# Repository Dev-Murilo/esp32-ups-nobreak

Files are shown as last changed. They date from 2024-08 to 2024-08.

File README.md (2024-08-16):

# esp32-ups-nobreak

## FIRST VIEW
Click here to go to the first view of main features, pins of 
[esp32-ups-nobreak](https://github.com/Dev-Murilo/esp32-ups-nobreak/tree/main/Doc)

##

O **esp32-ups-nobreak** é um projeto de nobreak (UPS - Uninterruptible Power Supply) que oferece suporte a diferentes aplicações devido à possibilidade de customização tanto por software quanto por hardware.

## Tabela de Conteúdo

- [Histórico do Projeto](#histórico-do-projeto)
  - [Primeira Versão](#primeira-versão)
  - [Segunda Versão](#segunda-versão)
  - [Terceira Versão (Atual)](#terceira-versão-atual)
- [Funcionalidades](#funcionalidades)
- [Configuração do Software Atual](#configuração-do-software-atual)
  - [Telemetria](#telemetria)
  - [Exemplo de Telemetria](#exemplo-de-telemetria)
- [Considerações sobre as Fontes de Alimentação](#considerações-sobre-as-fontes-de-alimentação)
- [Licença](#licença)

## Histórico do Projeto

### Primeira Versão
- Desenvolvido usando o uChip do Arduino Uno.
- Objetivo: Utilização com impressoras 3D.
- Status: Não entrou em produção.
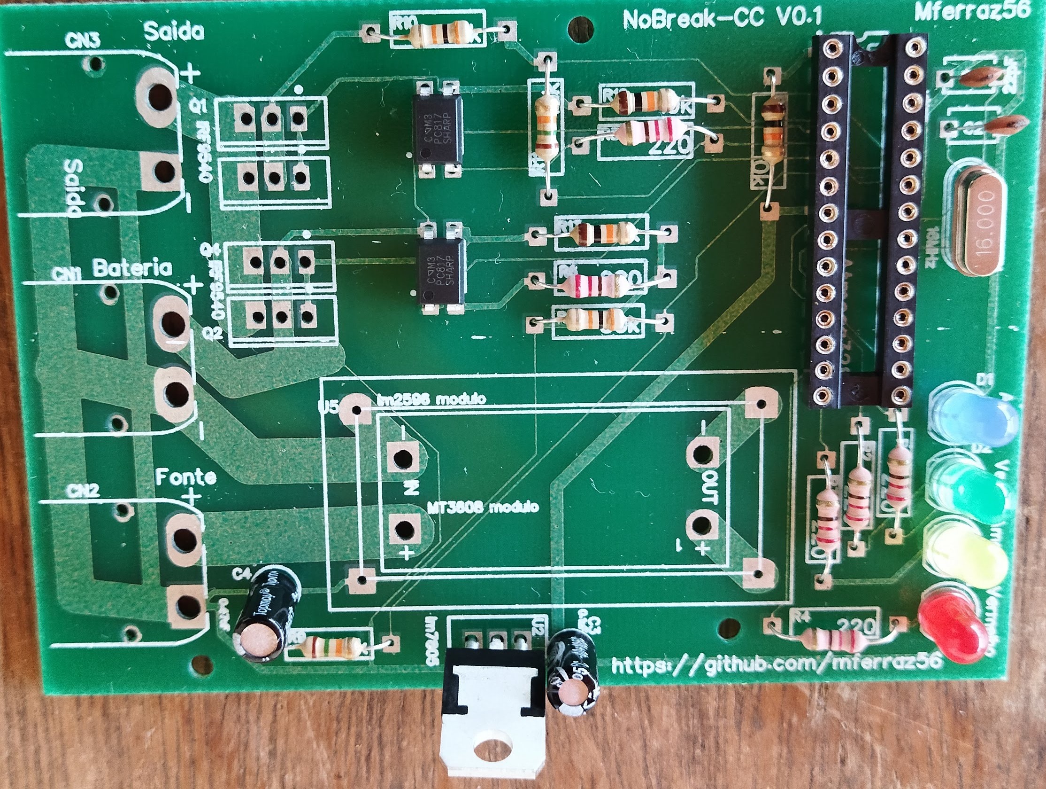
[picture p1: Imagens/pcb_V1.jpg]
pcb_V1


### Segunda Versão
- Critérios:
  - Utilização da menor área possível.
  - Teste e validação em tempo recorde.
  - Controle completo sobre baterias (qual alimenta a carga, qual é carregada, ordem de prioridade de carga e descarga).
  - Implementação de baterias V-mount.
- Status: Foi desenvolvido com sucesso.

### Terceira Versão (Atual)
- Utilização da placa de desenvolvimento **ESP32-S3 DevKit (44 pinos)**.
- Objetivo: Maior flexibilidade para controlar mais itens.
- Motivo da escolha da placa de desenvolvimento: Custo mais baixo em comparação ao embarque direto do ESP32 na PCB.
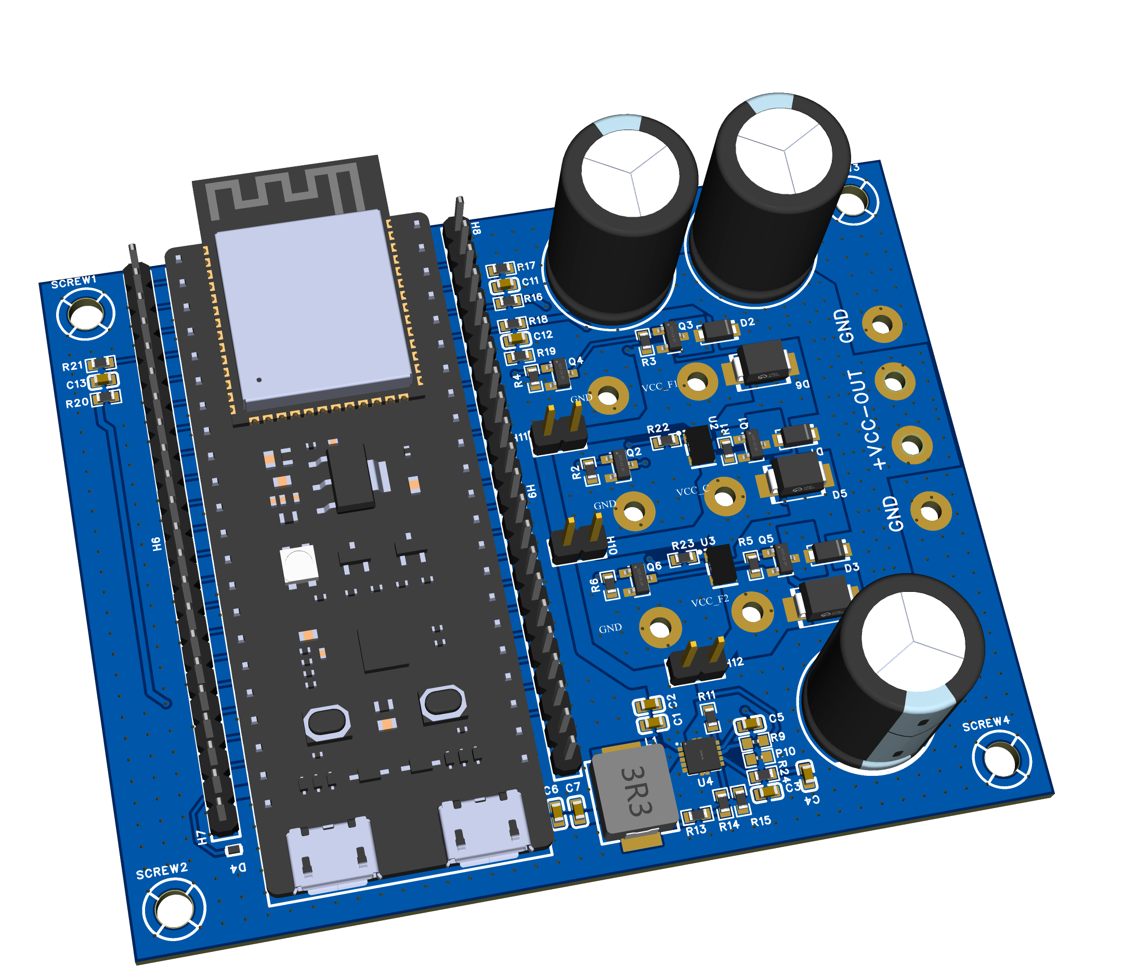
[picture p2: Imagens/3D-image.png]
3D-Image

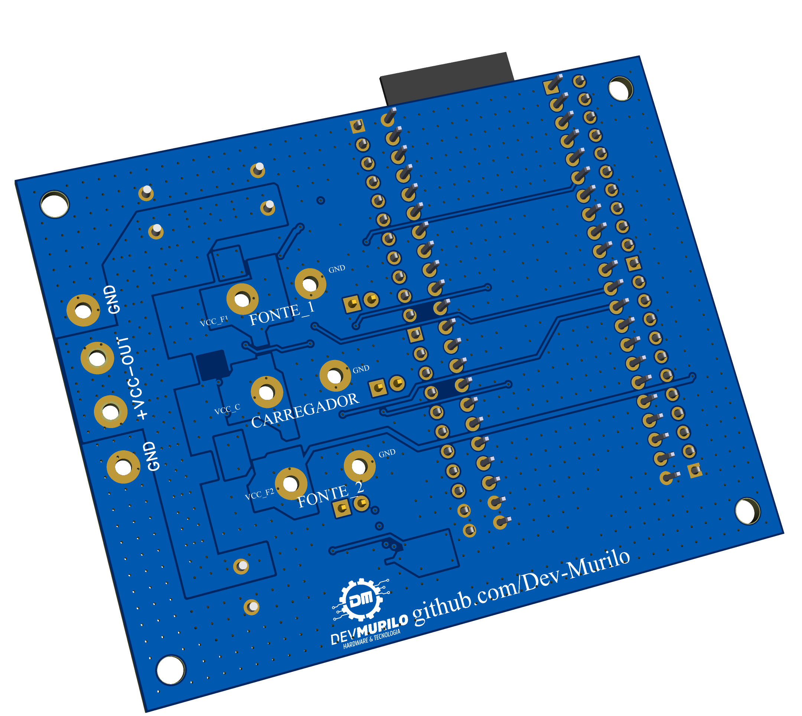
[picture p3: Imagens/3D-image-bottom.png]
3D-Image-bottom


## Funcionalidades

- **Entradas de Energia DC**: 3
- **Saída de Energia DC**: 1
- **Leitura ADC das entradas de energia**
- **Tomada de decisão com base nas leituras**
- **Sinais de Controle**: 5
  - 3 para controle de MOSFET (como chave para direcionar as entradas para a saída).
  - 2 para controle de relé SMD (para paralelizar fontes, como no caso de recarregar a bateria).

## Configuração do Software Atual

- O sistema realiza verificações e leituras das fontes disponíveis ao ligar.
- **Bateria Interna (Fonte 1)**: 
  - Usada como principal.
  - Prioridade em se manter carregada na presença de um carregador.
- **Bateria Externa**:
  - Prioridade na descarga.
  - Carregada apenas quando a bateria interna estiver totalmente carregada.
  - Quando ambas estiverem carregadas, os dois relés são acionados para manter as duas baterias carregadas durante o uso.
  
### Telemetria
- Exportada via serial ou USB em formato numérico: `(0,6,86,0,74)`
  - **0 ou 1**: Indica se a bateria externa está presente e sendo usada para alimentar o equipamento (1) ou se está ausente ou descarregada (0).
  - **0-1023**: Leitura ADC de 10 bits da tensão da bateria externa.
  - **0-1023**: Leitura ADC de 10 bits da tensão da bateria interna.
  - **0 ou 1**: Presença do carregador.
  - **0-1023**: Leitura ADC de 10 bits da tensão do carregador.

### Exemplo de Telemetria
[VEJA O VIDEO](https://youtu.be/NBOAWUM_bD8)

```plaintext
(0,6,86,0,74)
```

- **String Format**: `String(bateria_externa_conectada) + "," + String(Tensao_bateria_externa) + "," + String(Tensao_bateria) + "," + String(carregador_conectado) + "," + String(Tensao_carregador);`

## Considerações sobre as Fontes de Alimentação

- **Baterias V-mount**: Tensão nominal de 14.8V, 16.6V - 16.8V em carga máxima.
- **Fontes Maiores**: Podem causar danos nos circuitos destinados à potência.
- **Fontes Menores**: Requerem alterações no código para redefinição dos parâmetros.

## Licença
-Non-comercial usage without authorization.

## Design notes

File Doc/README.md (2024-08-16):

### This project aims to deliver power to the load so that it can have greater autonomy and decision-making capacity to supply loads that require monitoring and redundant operation with the possibility of hot-swapping the battery.

## Power output control circuits.

Here is the points that you can solder the cables. 
By default in the code, was made to use adc precision of 10 bits, because of the usage of another uC, the middle positions are configured to act as dc charger. 
#### Batery used to develop was Vmount 14,8V with the constant load not exceeding 3Amp

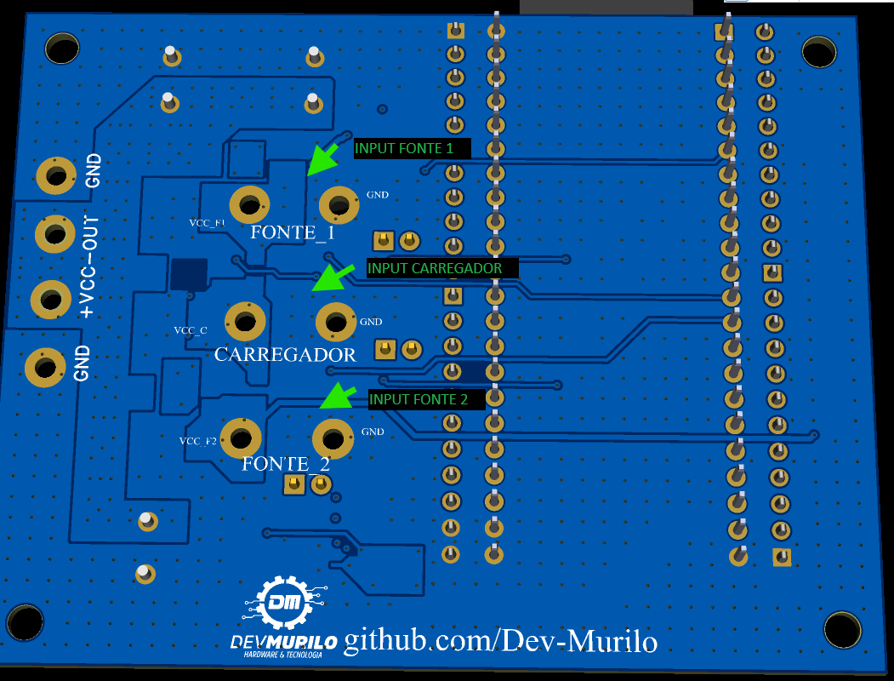
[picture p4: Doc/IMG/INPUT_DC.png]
Input_PCB


INPUT CARREGADOR:

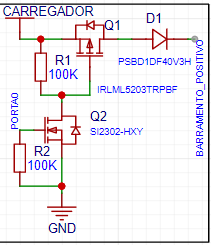
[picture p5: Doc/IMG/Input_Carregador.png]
Input_Carregador


INPUT FONTE1 

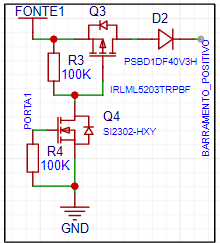
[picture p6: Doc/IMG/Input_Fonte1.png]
Input_Fonte1


INPUT FONTE2

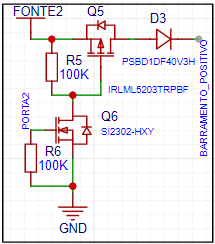
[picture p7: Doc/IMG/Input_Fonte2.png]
Input_Fonte1


## Circuit for source parallelism, Example of battery recharging use case.
You can use this relays to short circuit terminals form middle input and outer inputs, and you can monitoring dc charging and configure how it will work. Maximum of 3Amps

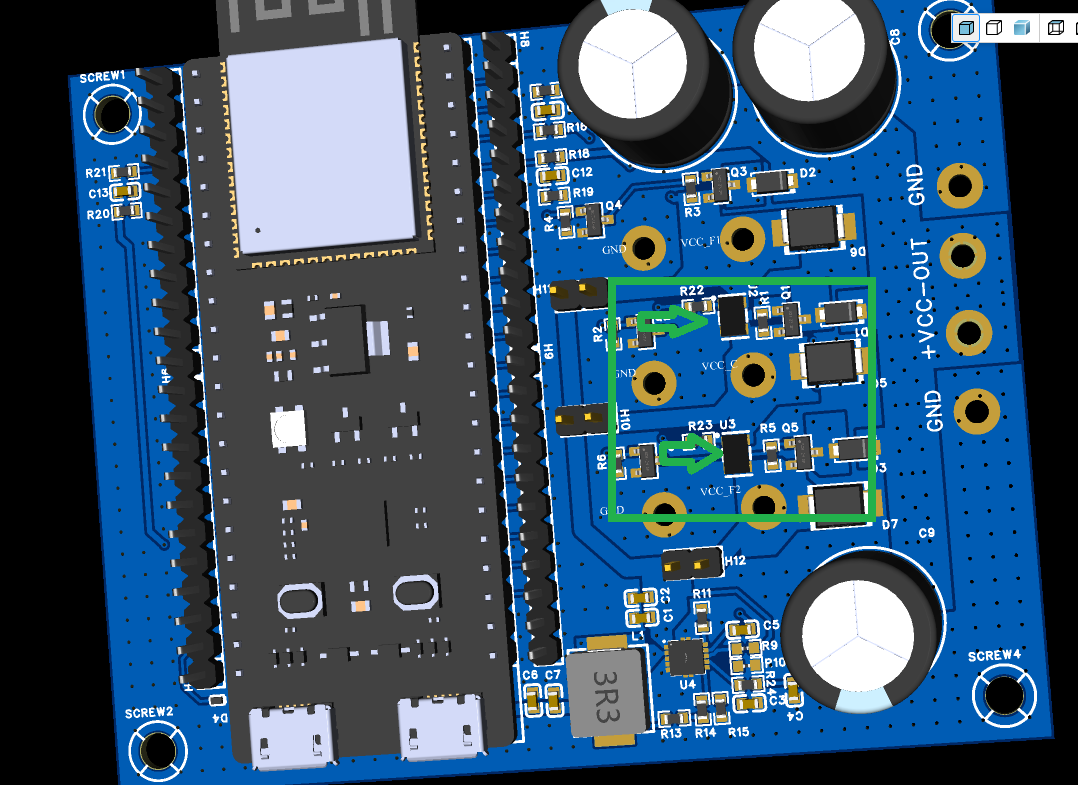
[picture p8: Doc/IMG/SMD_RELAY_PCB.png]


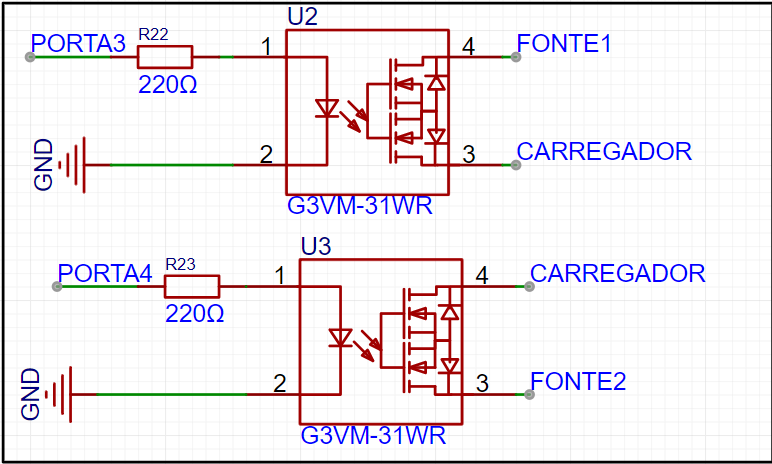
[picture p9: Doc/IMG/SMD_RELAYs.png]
SMD_RELAYs


## Circuit for ADC input and Voltage divider
Voltage divider circuit and reading: -- 25V to 3.3V

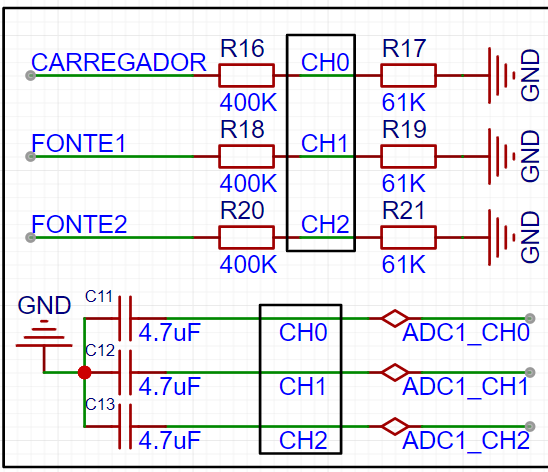
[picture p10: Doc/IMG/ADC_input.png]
ADC_input


## Circuito regulador stepdown 5V
Pins to set with suply will be used to act to maintain the uC. 

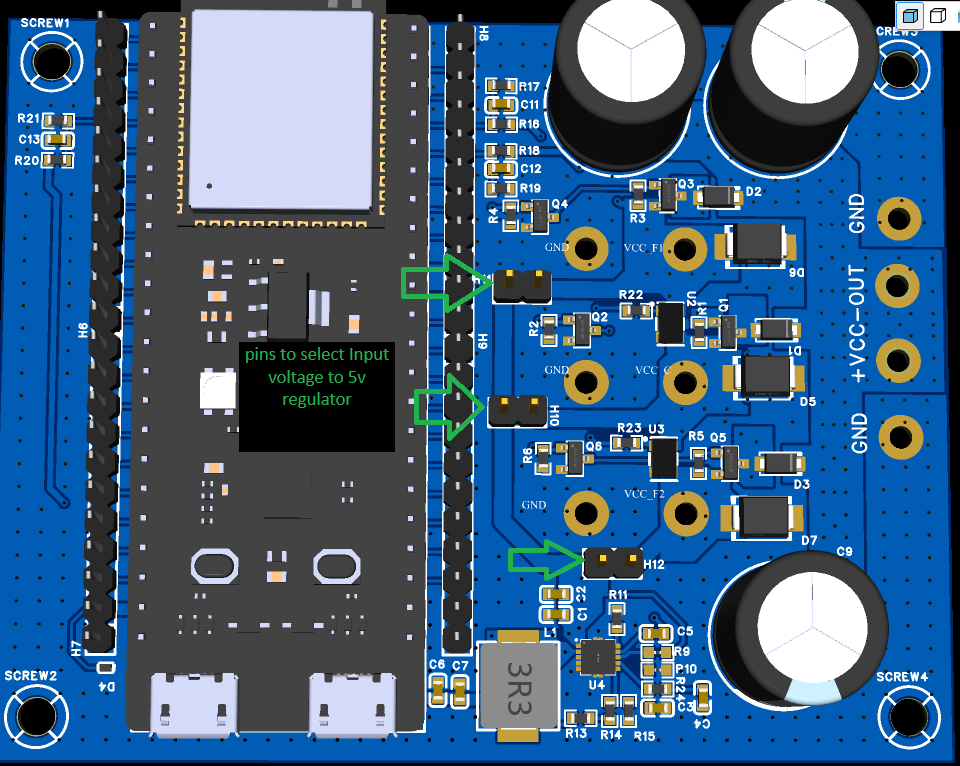
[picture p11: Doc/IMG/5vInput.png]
Stepdown-5v


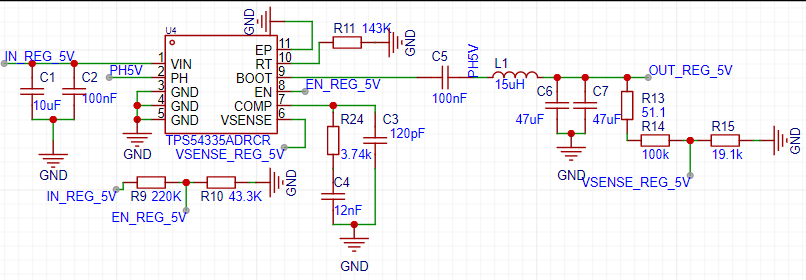
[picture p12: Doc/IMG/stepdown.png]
Stepdown


## ESD protections, Capacitor bank, Power buffer, Output bus
In red is the power buffer, to handle the time without suply in case of hotswap. 

In yelow is the output as gnd vcc vcc gnd.

In green is the esd components

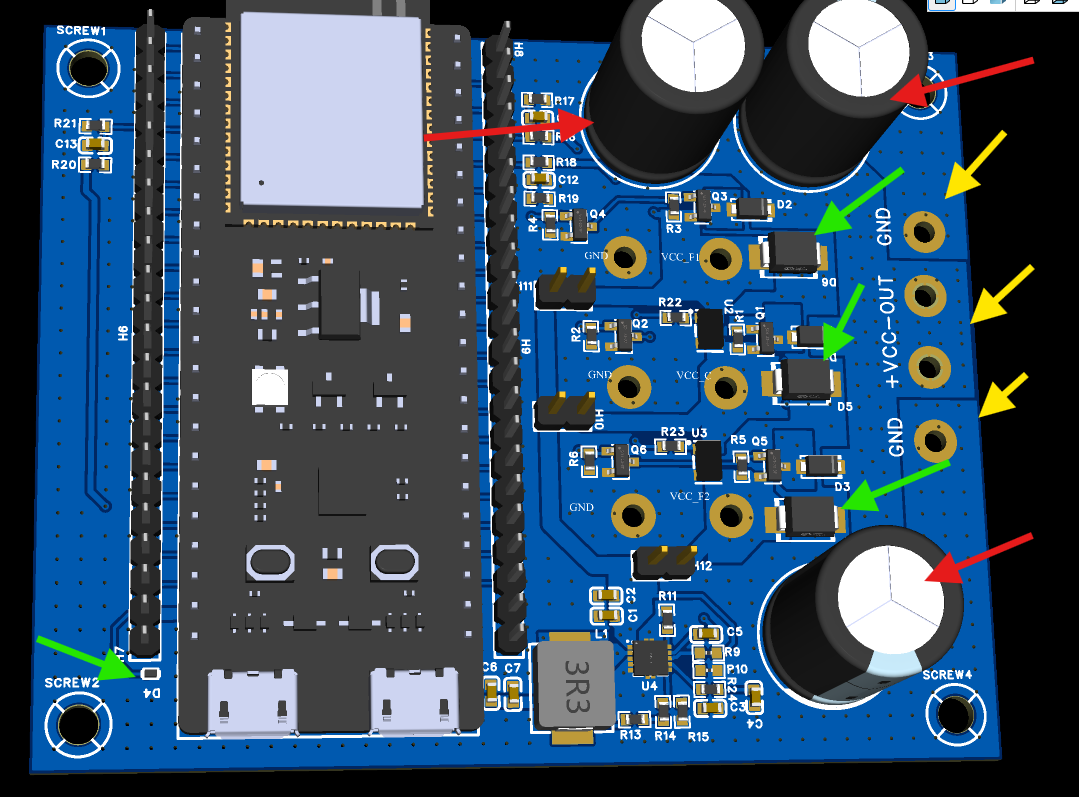
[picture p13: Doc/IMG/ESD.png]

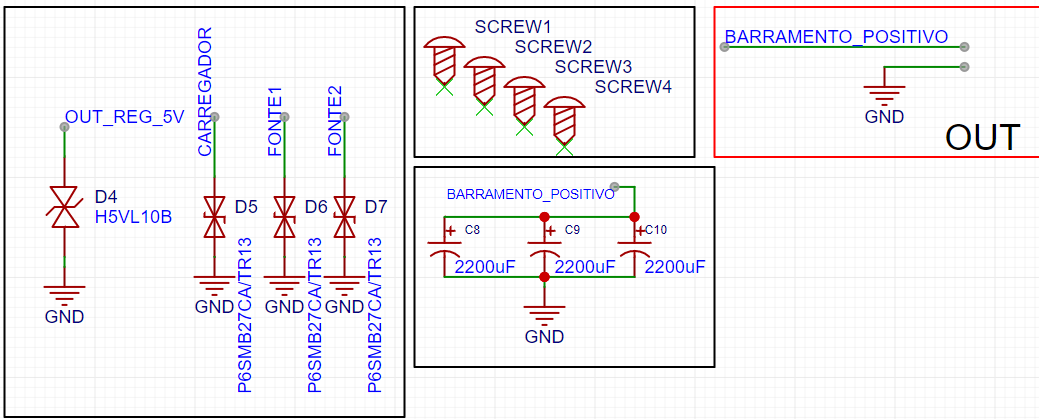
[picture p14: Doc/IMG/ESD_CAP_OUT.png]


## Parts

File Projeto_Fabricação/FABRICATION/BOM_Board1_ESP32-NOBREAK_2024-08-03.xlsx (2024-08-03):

No. | Quantity | Comment | Designator | Footprint | Value | Manufacturer Part | Manufacturer | Supplier Part | Supplier
1 | 1 | 10uF | C1 | C0603 | 10uF
2 | 2 | 100nF | C2,C5 | C0603 | 100nF
3 | 1 | 120pF | C3 | C0603 | 120pF
4 | 1 | 12nF | C4 | C0603 | 12nF
5 | 2 | 47uF | C6,C7 | C0603 | 47uF
6 | 3 | 2200uF | C8,C9,C10 | CAP-TH_BD13.0-P5.00-D0.6-FD | 2200uF | GR228M035J25RR0VH4FP0 | CX(承兴) | C43275 | LCSC
7 | 3 | 4.7uF | C11,C12,C13 | C0603 | 4.7uF | CL10A475KP8NNNC | SAMSUNG(三星) | C1705 | LCSC
8 | 3 | PSBD1DF40V3H | D1,D2,D3 | SOD-123FL_L2.8-W1.8-LS3.7-RD |  | PSBD1DF40V3H | Prisemi(芯导) | C918826 | LCSC
9 | 1 | H5VL10B | D4 | SOD-882_L1.0-W0.6-BI |  | H5VL10B | 宏迦橙 | C7420372 | LCSC
10 | 3 | P6SMB27CA/TR13 | D5,D6,D7 | SMB_L4.3-W3.6-LS5.4-BI |  | P6SMB27CA/TR13 | Brightking(君耀电子) | C730015 | LCSC
11 | 4 | HDR-M_2.54_1x11P | H6,H7,H8,H9 | HDR-TH_11P-P2.54-V-M
12 | 3 | B-2100S02P-A110 | H10,H11,H12 | HDR-TH_2P-P2.54-V-M-1 |  | B-2100S02P-A110 | Ckmtw(灿科盟) | C124375 | LCSC
13 | 1 | 15uH | L1 | IND-SMD_L7.5-W6.6 | 15uH | CKST0605-15uH/M | CENKER(岑科) | C3002651 | LCSC
14 | 3 | IRLML5203TRPBF | Q1,Q3,Q5 | SOT-23-3_L2.9-W1.3-P1.90-LS2.4-BR |  | IRLML5203TRPBF | Infineon(英飞凌) | C2592 | LCSC
15 | 3 | SI2302-HXY | Q2,Q4,Q6 | SOT-23-3_L2.9-W1.3-P1.90-LS2.4-BR |  | SI2302-HXY | HXY MOSFET(华轩阳电子) | C4748714 | LCSC
16 | 6 | 100K | R1,R2,R3,R4,R5,R6 | R0603 | 100K
17 | 1 | 220K | R9 | R0603 | 220K
18 | 1 | 43.3K | R10 | R0603 | 43.3K
19 | 1 | 143K | R11 | R0603 | 143K
20 | 1 | 51.1 | R13 | R0603 | 51.1
21 | 1 | 100k | R14 | R0603 | 100k
22 | 1 | 19.1k | R15 | R0603 | 19.1k
23 | 3 | 400K | R16,R18,R20 | R0603 | 400K
24 | 3 | 61K | R17,R19,R21 | R0603 | 61K
25 | 2 | 220Ω | R22,R23 | R0603 | 220Ω | 0603WAF2200T5E | UNI-ROYAL(厚声) | C22962 | LCSC
26 | 1 | 3.74k | R24 | R0603 | 3.74k
27 | 4 | Screw-Hole-M3 | SCREW1,SCREW2,SCREW3,SCREW4 | Screw-Hole-M3
28 | 1 | ESP32-S3-DEVKITC-1 | U1 | ESP32-S3-DEVKITC-1 |  | ESP32-S3-DEVKITC-1U-N8R8 | Espressif | 1965-ESP32-S3-DEVKITC-1U-N8R8-ND | DigiKey
29 | 2 | G3VM-31WR | U2,U3 | OPTO-SMD_OMRON_G3VM-31WR |  | G3VM-31WR |  | C9900059545 | LCSC
30 | 1 | TPS54335ADRCR | U4 | VSON-10_L3.0-W3.0-P0.50-TL-EP |  | TPS54335ADRCR | TI(德州仪器) | C473400 | LCSC

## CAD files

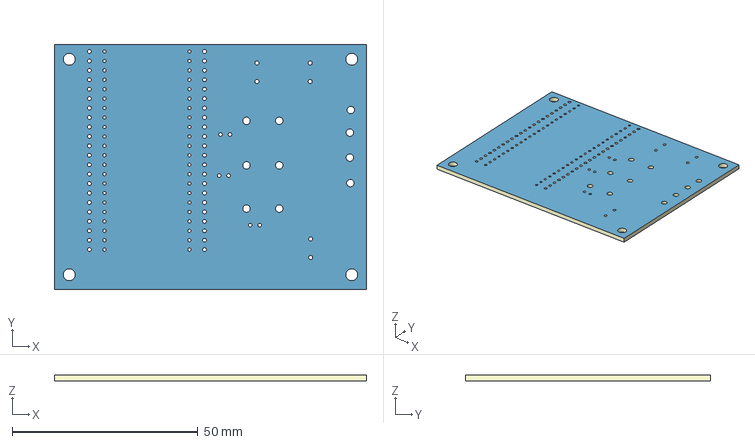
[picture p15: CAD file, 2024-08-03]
Modelo_3d/3D_PCB.step
84.0 x 66.0 x 1.59 mm

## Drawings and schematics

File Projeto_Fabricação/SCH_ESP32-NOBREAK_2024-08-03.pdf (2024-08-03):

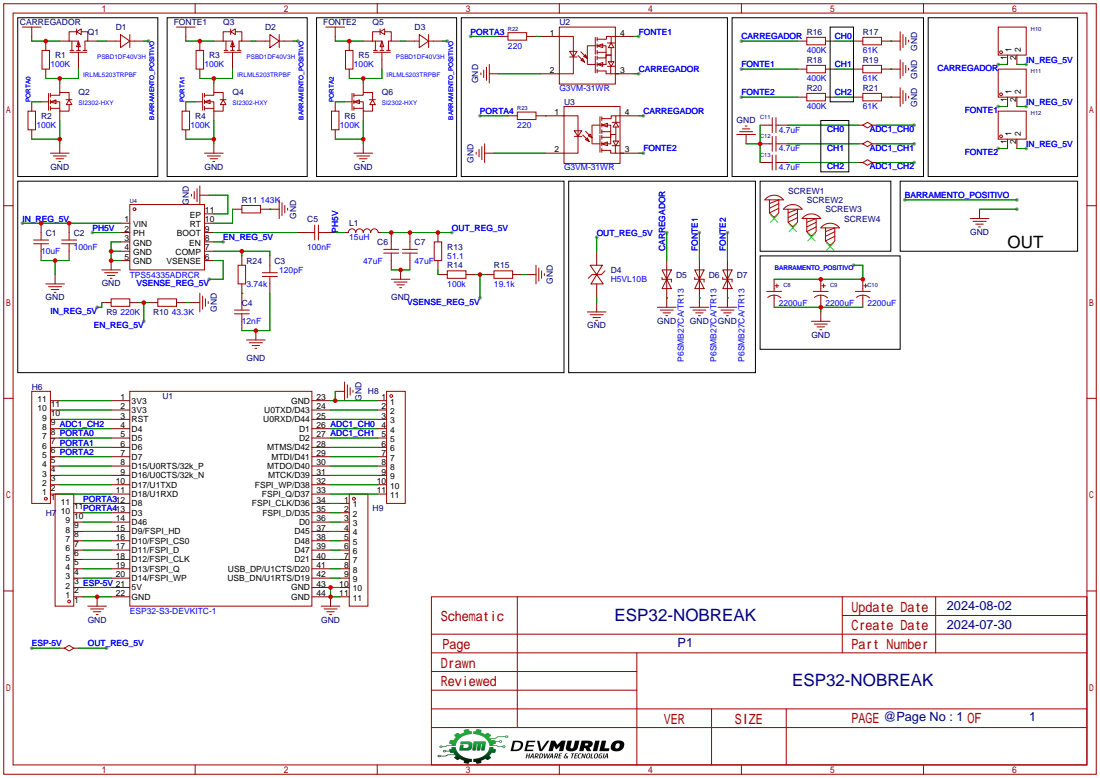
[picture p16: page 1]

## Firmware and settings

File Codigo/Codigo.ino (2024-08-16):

/* 

@Dev_Murilo - email: contato@devmurilo.com.br

*/
#include <stdio.h>
//unsigned long int time;  //variavel

//tring to implment softstart

//### variaveis para leitura do ADC de cada porta de entrada
int Tensao_carregador = 0;       // variavel tensão carregadpr
int Tensao_bateria = 0;          // variavel tensão bateria interna
int Tensao_bateria_externa = 0;  // variavel tensão bateria externa

//#### portas de saida destinadas a controle dos mosfets
int carregador = 5;       // porta de controle de mosfet carrergador
int bateria = 6;          // porta de controle de mosfet bateria
int bateria_externa = 7;  // porta de controle de mosfet bateria externa
int rele_bat = 8;              // porta de controle de rele
int rele_bat2 = 3;              // porta de controle de rele

//### variaveis para salvar estados do sistema
bool bateria_carregada = true;
bool bateria_externa_carregada = false;
bool carregador_conectado = false;
bool bateria_externa_conectada = false;
bool bateria_conectada = true;

// 0% = 530
// 100% = 675

//## variaveis para contador comunicação serial
unsigned long previousMillis = 0; 
unsigned long previousMillis2= 0; 
const long interval = 1000;       
const long interval2 = 10000;
unsigned long currentMillis = millis();

// softstart
bool softstartComplete = false; // Flag de softstart completo
const int pwmPin = bateria; // Pino PWM para controle do softstart
const int softstartTime = 5000; // Tempo de duração do softstart em milissegundos

void setup() {
  Serial1.begin(115200);  
  Serial.begin(115200); 
  analogReadResolution(10); 
  
  pinMode(carregador, OUTPUT);       // saida mosfet carregador + led azul
  pinMode(bateria, OUTPUT);          // saida Mosfet bateria 1 + led verde
  pinMode(bateria_externa, OUTPUT);  // saida mosfet bateria 2 + led amarelo
  
  
  pinMode(rele_bat, OUTPUT);            // carregar bateria interna
  pinMode(rele_bat2, OUTPUT);            // carregar bateria externa

  //#### fazendo varredura inicial bateria interna
  
  Tensao_bateria = analogRead(2);
  //Serial.println("tensão da bateria: ");
  //Serial.print(Tensao_bateria);
  //Serial.println("");

  //if(Tensao_bateria<=530){
  //  bateria_carregada=false;
  //}else digitalWrite(bateria,HIGH)  
  if(Tensao_bateria<=530){
    bateria_carregada=false;
  }else softstart();

  //#### fazendo varredura inicial bateria externa
  Tensao_bateria_externa = analogRead(4);
  //Serial.println("tensão da bateria externa: ");
  //Serial.print(Tensao_bateria_externa);
  //Serial.println("");
  if (Tensao_bateria_externa <= 200) {
    bateria_externa_carregada = false;
    bateria_externa_conectada = false;
  } else {
    bateria_externa_conectada = true;
  }
  if (Tensao_bateria_externa >= 540) {
    bateria_externa_carregada = true;
  }
  
  //time = millis();
  //Serial.println("Tempo decorrido para setup");
  //Serial.println(time);
}


// Soft start function
void softstart(){
  while (pwmValue < 1023) {
        analogWrite(pwmPin, pwmValue);
        pwmValue += increment;
        delay(softstartTime / (1023 / increment));
    }
    softstartComplete = true;
    return;
}

void loop() {
    Tensao_carregador = analogRead(1);
    Tensao_bateria = analogRead(2);
    Tensao_bateria_externa = analogRead(4);  
    {  // VERIFICA BATERIA EXTERNA
      if(Tensao_bateria_externa<=540){
        bateria_externa_carregada=false;
        bateria_externa_conectada=false;
      }
      if(Tensao_bateria_externa>=580){
          bateria_externa_carregada=true;
          bateria_externa_conectada=true;
      }

      // bateria carregada e conectada
      if(bateria_externa_carregada==true && bateria_externa_conectada==true){
      //Serial.println("CONDIÇÃO E");

      digitalWrite(bateria_externa,HIGH);
      delay(1);
      digitalWrite(bateria,LOW);
      bateria_conectada=false;
      }

      // bateria ausente externa desconectada ou descarregada e a interna carregada
      if(bateria_externa_carregada==false || bateria_externa_conectada==false && bateria_carregada==true){
      //Serial.println("CONDIÇÃO OU");
      digitalWrite(bateria,HIGH);
      delay(1);
      digitalWrite(bateria_externa,LOW);
      }
    }
    { // verifica carregador
      if(currentMillis - previousMillis2 >= interval2) {
        previousMillis2 = currentMillis; // salva o tempo atual

        digitalWrite(rele_bat2,LOW);
        digitalWrite(rele_bat,LOW);
        digitalWrite(bateria,HIGH);
        delay(1);
        digitalWrite(bateria_externa,LOW);
        delay(1);
        Tensao_carregador=analogRead(A0);
        Tensao_bateria_externa=analogRead(A2);
        if(Tensao_carregador>=400){
          carregador_conectado=true;
        } else carregador_conectado = false;
        
        if(carregador_conectado==true){
          if(Tensao_bateria_externa>=100){
            if(Tensao_bateria>=675){
              digitalWrite(rele_bat2,HIGH);
              digitalWrite(rele_bat,LOW);
            }
            else {
            digitalWrite(rele_bat2,LOW);
            digitalWrite(rele_bat,HIGH);
            }  
          } else {
            digitalWrite(rele_bat2,LOW);
            digitalWrite(rele_bat,HIGH);
          
          }
          if(Tensao_bateria>=675 && Tensao_bateria_externa>= 675){
            digitalWrite(rele_bat2,HIGH);
            digitalWrite(rele_bat,HIGH);
            Serial.println("CARREGANDO AS DUAS");
          }
        } else {
          digitalWrite(rele_bat2,LOW);
          digitalWrite(rele_bat,LOW);
        }
        
      }
    }
      
  // envia informações  
  if (currentMillis - previousMillis >= interval) {
    // bateria externa conectada 0 ou 1 , tensão externa, tensão bateria interna, 
    String Concatenada = String(bateria_externa_conectada)+","+String(Tensao_bateria_externa)+","+String(Tensao_bateria)+","+String(carregador_conectado)+","+String(Tensao_carregador);
    previousMillis = currentMillis; // salva o tempo atual
    Serial1.println(Concatenada); 
    Serial.println(Concatenada);  
  }  
  //String Concatenada = String(bateria_externa_conectada)+","+String(Tensao_bateria_externa)+","+String(Tensao_bateria)+","+String(Tensao_carregador);
  //Serial.println(Concatenada);  

  currentMillis = millis();
}

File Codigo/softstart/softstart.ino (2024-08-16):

#include <Arduino.h>

bool softstartComplete = false; // Flag de softstart completo
const int pwmPin = 4; // Pino PWM para controle do softstart
const int softstartTime = 10000; // Tempo de duração do softstart em milissegundos

void softstart() {
    Serial.println("Softstart");
    int pwmValue = 0;
    int increment = 1;

    // Aumenta gradualmente o valor do PWM até atingir o máximo
    while (pwmValue < 1023) {
        analogWrite(pwmPin, pwmValue);
        pwmValue += increment;
        delay(softstartTime / (1023 / increment));
    }

    /*
    // Mantém o valor máximo do PWM por um tempo
    delay(softstartTime);

    
    // Diminui gradualmente o valor do PWM até desligar completamente
    while (pwmValue > 0) {
        analogWrite(pwmPin, pwmValue);
        pwmValue -= increment;
        delay(softstartTime / (1023 / increment));
    }

    // Desliga o PWM
    analogWrite(pwmPin, 0);
  */  
    softstartComplete = true;
    return;
}

void setup() {
    pinMode(pwmPin, OUTPUT);
    Serial.begin(115200);
    Serial.println("saindo Setup");
}

void loop() {
    Serial.println("entrando Loop");
    // Chama a função de softstart
    if(softstartComplete!=true) {
        //softstart();
    }
    analogWrite(pwmPin,1);
    delay(1000);
     
}
